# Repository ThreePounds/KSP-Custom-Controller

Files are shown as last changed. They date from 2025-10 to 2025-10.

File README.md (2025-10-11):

# KSP-Custom-Controller

This is a custom built game controller with 12 buttons and 7 analog axis using a teensy 4.0 and a 3D-printed housing designed for Kerbal Space Program. It's heavily inspired by [ksp-controller](https://github.com/malarcky/ksp-controller/) by *malarcky*.

## Setting up the custom controller

The teensy 4.0 micro controller is programmed using Arduino IDE and a custom USB type. To create the custom USB type, changes are made to the following files found in the teensy package. For me on windows, these files are located in `%appdata%\Local\Arduino15\packages\teensy\hardware\avr\1.59.0\cores\teensy4`.

### usb_desc.h

This code sets up the USB type and can be inserted any where after the first `#if defined()`:
```
#elif defined(USB_CUSTOM_CONTROLLER)
	#define VENDOR_ID 0x16C0
	#define PRODUCT_ID 0x0488
	#define BCD_DEVICE 0x0211
	#define MANUFACTURER_NAME {'T','h','r','e','e','P','o','u','n','d','s'}
	#define MANUFACTURER_NAME_LEN 11
	#define PRODUCT_NAME {'C','u','s','t','o','m',' ','K','S','P',' ','C','o','n','t','r','o','l','l','e','r'}
	#define PRODUCT_NAME_LEN 21
	#define EP0_SIZE 64
	#define NUM_ENDPOINTS 3
	#define NUM_INTERFACE 2
	#define SEREMU_INTERFACE 1 // Serial emulation
	#define SEREMU_TX_ENDPOINT 2
	#define SEREMU_TX_SIZE 64
	#define SEREMU_TX_INTERVAL 1
	#define SEREMU_RX_ENDPOINT 2
	#define SEREMU_RX_SIZE 32
	#define SEREMU_RX_INTERVAL 2
	#define JOYSTICK_INTERFACE 2 // Joystick
	#define JOYSTICK_ENDPOINT 3
	#define JOYSTICK_SIZE 16 // 16 = custom game controller, 12 = normal joystick, 64 = extreme joystick
	#define JOYSTICK_INTERVAL 1
	#define ENDPOINT2_CONFIG ENDPOINT_RECEIVE_INTERRUPT + ENDPOINT_TRANSMIT_INTERRUPT
	#define ENDPOINT3_CONFIG ENDPOINT_RECEIVE_UNUSED + ENDPOINT_TRANSMIT_INTERRUPT
```

### usb_joystick.h

This handles this axis and button assignment and must be added before the line `#elif JOYSTICK_SIZE == 64`.

```
#elif JOYSTICK_SIZE == 16 // Modified for 7-Axis, 12-Button, 16-Byte Report
	/**
	 * Sets the state of a button (1-12).
	 */
	void button(unsigned int num, bool val) {
		if (--num >= 12) return;
		// The 12 buttons fit in the first 16-bit word of the report.
		uint16_t *p = (uint16_t *)usb_joystick_data;
		if (val) {
			*p |= (1 << num);
		} else {
			*p &= ~(1 << num);
		}
		if (!manual_mode) usb_joystick_send();
	}

	// Axis Functions (public interface remains the same)
	void X(unsigned int position) { analog16(0, position); }
	void Y(unsigned int position) { analog16(1, position); }
	void Z(unsigned int position) { analog16(2, position); }
	void Xrotate(unsigned int position) { analog16(3, position); }
	void Yrotate(unsigned int position) { analog16(4, position); }
	void Zrotate(unsigned int position) { analog16(5, position); }

	/**
	 * Sets the position of the 7th axis (Slider).
	 * The original 'num' parameter is removed as we only have one slider.
	 */
	void slider(unsigned int position) {
		analog16(6, position);
	}
```

In the `private:` section before the line `#if JOYSTICK_SIZE == 64` add:

```
#if JOYSTICK_SIZE == 16
	void analog16(unsigned int num, unsigned int value) {
		if (num >= 7) return; // Safety check for 7 axes
		if (value > 1023) value = 1023;
		uint16_t scaled_value = (value << 6) | (value >> 4);
		
		uint16_t *p = (uint16_t *)usb_joystick_data;
		
		p[num + 1] = scaled_value;

		if (!manual_mode) usb_joystick_send(); 
	}
#endif
```

## 3D-printed housing

The housing was modelled using FreeCad 1.0.2. Included are .3mf files for the face plate and housing so they can be printed separately.

## The finished controller

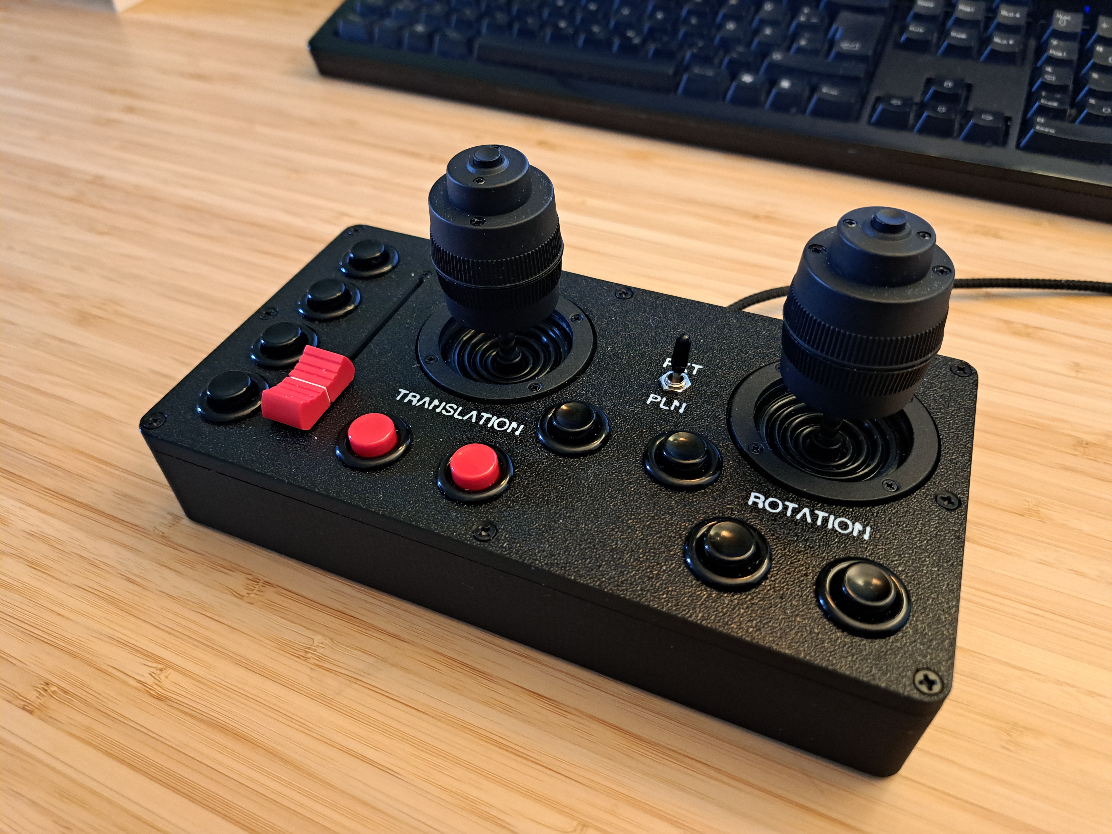
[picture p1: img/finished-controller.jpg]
the finished controller sitting on a desk


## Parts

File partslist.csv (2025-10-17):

Part | Link | Amount | Price | Total
LITZE RT Insulated braided copper wire, 10 m, 1 x 0.14 mm, red | https://secure.reichelt.com/de/en/insulated_braided_copper_wire_10_m_1_x_0_14_mm_red-p10297.html | 1 | 0.93 € | 0.93 €
LITZE BL Insulated braided copper wire, 10 m, 1 x 0.14 mm, blue | https://secure.reichelt.com/de/en/insulated_braided_copper_wire_10_m_1_x_0_14_mm_blue-p10292.html | 1 | 0.93 € | 0.93 €
LITZE GE Insulated braided copper wire, 10 m, 1 x 0.14 mm, yellow | https://secure.reichelt.com/de/en/insulated_braided_copper_wire_10_m_1_x_0_14_mm_yellow-p10294.html | 1 | 0.93 € | 0.93 €
LITZE SW Insulated braided copper wire, 10 m, 1 x 0.14 mm, black | https://secure.reichelt.com/de/en/insulated_braided_copper_wire_10_m_1_x_0_14_mm_black-p10298.html | 1 | 0.93 € | 0.93 €
KNOPF 4X1,2RT Fader knob for RS60112, rd | https://secure.reichelt.com/de/en/fader_knob_for_rs60112_rd-p73946.html | 1 | 1.25 € | 1.25 €
MS 165 Toggle switch, 1-pin, 10 A - 125 V AC, on-of | https://secure.reichelt.com/de/en/toggle_switch_1-pin_10_a_-_125_v_ac_on-off-p13139.html | 1 | 2.50 € | 2.50 €
MS 131 SW Push button miniature, 3 A - 125 V, 1x on, black | https://secure.reichelt.com/de/en/push_button_miniature_3_a_-_125_v_1x_on_black-p13137.html | 8 | 1.25 € | 10.00 €
MS 131 RT Push button miniature, 3 A - 125 V, 1x on, red | https://secure.reichelt.com/de/en/push_button_miniature_3_a_-_125_v_1x_on_red-p13136.html | 2 | 1.50 € | 3.00 €
RS60112-LIN10K ALPS mini sliding potentiometer, linear, stereo, 10K | https://secure.reichelt.com/de/en/alps_mini_sliding_potentiometer_linear_stereo_10k-p73865.html | 1 | 3.10 € | 3.10 €
TEENSY 4.0 Teensy 4.0, USB, without header | https://secure.reichelt.com/de/en/teensy_4_0_usb_without_header-p269006.html | 1 | 29.50 € | 29.50 €
Toocki 2.4A Micro USB Cable Fast Charging PD QC Quick Charge Micro Cable for Samsung S6 S7 Redmi Note Earphone Fan USB Data Cord | https://de.aliexpress.com/item/1005007053790042.html | 1 | 2.49 € | 2.49 €
JH-D400X-R4 JH-D400X-R2 4-axis potentiometer 400 series Rocker hall joystick dimensional 5K 10K sealed with button joystick | https://de.aliexpress.com/item/1005001844154962.html | 2 | 13.29 € | 26.58 €
Selbstklebend Gummi Scheiben Rund Gummipads Platte Φ 5mm bis 150mm Dicke 1-10mm, Durchmesser x Dicke: Φ10mm x 2mm, Menge (Stück): 10 Stück | https://www.ebay.de/itm/388732033051?var=655838041427 | 1 | 3.78 € | 3.78 €
M2 M2.5 M3 Senkkopfschrauben Kreuzschlitz Schrauben DIN 965, Schwarz Verzinkt, Gewindedurchmesser: M3 / 3mm, Menge (Stück): 10pcs, Länge: 10mm | https://www.ebay.de/itm/388667186919?var=655768644411 | 1 | 3.07 € | 3.07 €
M2 M2.5 M3 Senkkopfschrauben Kreuzschlitz Schrauben DIN 965, Schwarz Verzinkt, Gewindedurchmesser: M2 / 2mm, Menge (Stück): 10pcs, Länge: 5mm | https://www.ebay.de/itm/388667186919?var=655768644339 | 1 | 1.89 € | 1.89 €
3D printing, threaded inserts, VORON, M3, pack of 100 | https://www.reichelt.com/de/en/shop/product/3d_printing_threaded_inserts_voron_m3_pack_of_100-367014 | 1 | 9.49 € | 9.49 €
3D print, filament cost (approx.) |  | 1 | 10.51 € | 10.51 €
Total |  |  |  | 110.88 €

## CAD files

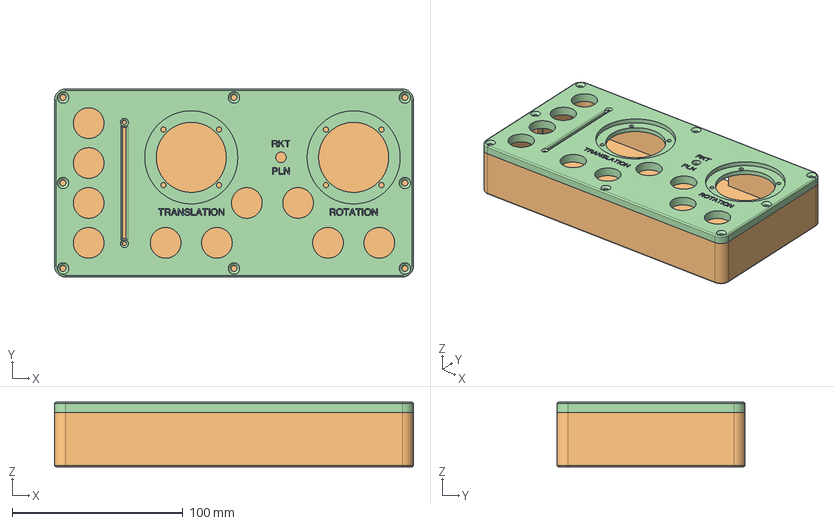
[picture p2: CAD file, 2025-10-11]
3d-models/ksp-controller.FCStd
210.0 x 110.0 x 38.0 mm
faceplate
housing
textElemets
faceplateCut

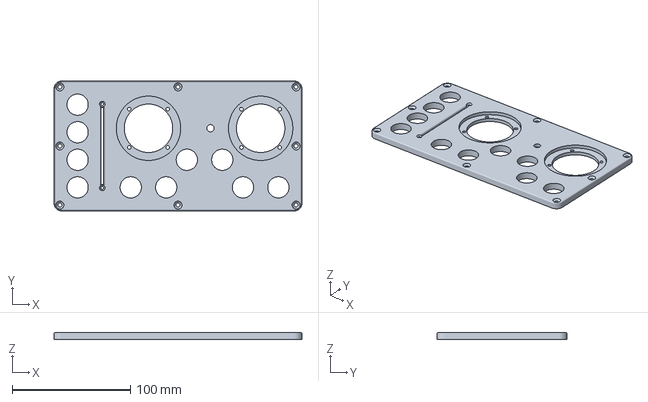
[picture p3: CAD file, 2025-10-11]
3d-models/ksp-controller_FacePlate.3mf
210.0 x 110.0 x 6.00 mm

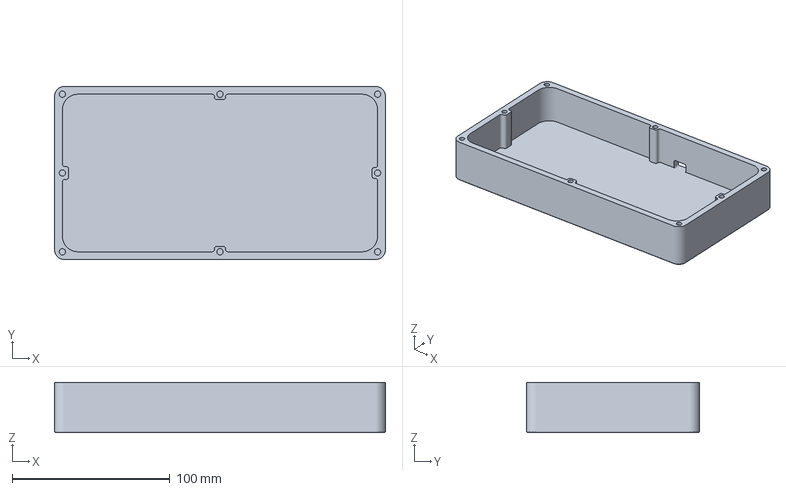
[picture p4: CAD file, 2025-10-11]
3d-models/ksp-controller_Housing.3mf
210.0 x 110.0 x 32.0 mm

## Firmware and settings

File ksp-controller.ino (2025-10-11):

//use UBS-Type "Custom Game Controller"
//see: https://github.com/ThreePounds/KSP-Custom-Controller for instructions

#include <Bounce2.h>  // debouncing

int BUTTON_PINS[] = { 0, 1, 5, 6, 11, 10, 9, 8, 7, 3, 4, 2 };
const int BUTTON_NUMBER = 12;
const int SWITCH_PIN = 12; // used for switching between spacecraft mode (normal) and aircraft mode (x-asis and z-axis on rotation joystick swapped)
const int JOY1_X_PIN = A4;
const int JOY1_Y_PIN = A3;
const int JOY1_Z_PIN = A5;
const int JOY2_X_PIN = A0;
const int JOY2_Y_PIN = A1;
const int JOY2_Z_PIN = A2;
const int SLIDER_PIN = A7;
const int ANALOG_MAX = 1023;
const int ANALOG_CENTER = 512;

Bounce2::Button buttonBouncers[BUTTON_NUMBER];
Bounce2::Button switchBouncer;

const int DEBOUNCE_MS = 10;

bool planeMode = false;

struct JoystickState {
  int xRaw;
  int yRaw;
  int zRaw;  
  float x;
  float y;
  float z;
};

JoystickState joystick1;
JoystickState joystick2;

int sliderRaw = 0;
float sliderValue = 0;

unsigned long lastUpdateTime = 0;
const int UPDATE_INTERVAL_MS = 5;

void setup() {
  for (int i = 0; i < BUTTON_NUMBER; i++) {
    buttonBouncers[i].attach(BUTTON_PINS[i], INPUT_PULLUP);
    buttonBouncers[i].interval(DEBOUNCE_MS);
  }
  switchBouncer.attach(SWITCH_PIN, INPUT_PULLUP);
  Joystick.useManualSend(true);
}

void loop() {
  switchBouncer.update();
  for (int i = 0; i < BUTTON_NUMBER; i++) {
    buttonBouncers[i].update();
  }

  if (millis() - lastUpdateTime >= UPDATE_INTERVAL_MS) {
    lastUpdateTime = millis();

    planeMode = !switchBouncer.read();

    joystick1.xRaw = ANALOG_MAX - analogRead(JOY1_X_PIN); //potentiometer soldered inverted by accident
    joystick1.yRaw = analogRead(JOY1_Y_PIN);
    joystick1.zRaw = analogRead(JOY1_Z_PIN);
    
    joystick1.x = applySmoothing(applyDeadzone(joystick1.xRaw), joystick1.x); 
    joystick1.y = applySmoothing(applyDeadzone(joystick1.yRaw), joystick1.y);
    joystick1.z = applySmoothing(applyDeadzone(joystick1.zRaw), joystick1.z);

    joystick2.xRaw = ANALOG_MAX - analogRead(JOY2_X_PIN); //potentiometer soldered inverted by accident
    joystick2.yRaw = ANALOG_MAX - analogRead(JOY2_Y_PIN); //potentiometer soldered inverted by accident
    joystick2.zRaw = analogRead(JOY2_Z_PIN);

    joystick2.x = applySmoothing(applyDeadzone(joystick2.xRaw), joystick2.x);
    joystick2.y = applySmoothing(applyDeadzone(joystick2.yRaw), joystick2.y);
    joystick2.z = applySmoothing(applyDeadzone(joystick2.zRaw), joystick2.z);

    //Right Joystick
    if (planeMode) {
      Joystick.X(applyExpoCurve(joystick1.z)); //assigning roll to jaw
      Joystick.Z(applyExpoCurve(joystick1.x)); //assigning jaw to roll
    } else {
      Joystick.X(applyExpoCurve(joystick1.x));
      Joystick.Z(applyExpoCurve(joystick1.z));
    }

    Joystick.Y(applyExpoCurve(joystick1.y));

    //Left Joystick
    Joystick.Xrotate(applyExpoCurve(joystick2.x));
    Joystick.Yrotate(applyExpoCurve(joystick2.y));
    Joystick.Zrotate(applyExpoCurve(joystick2.z));

    //slider
    sliderRaw = ANALOG_MAX - analogRead(SLIDER_PIN); //soldered inverted
    sliderValue = applySmoothing(sliderRaw, sliderValue);
    Joystick.slider(sliderValue);

    for (int i = 0; i < BUTTON_NUMBER; i++) {
      Joystick.button(i + 1, !buttonBouncers[i].read());
    }
    
    Joystick.send_now();
  }
}

int applyDeadzone(int value) {
  const int DEADZONE_RADIUS = 20;

  if (abs(value - ANALOG_CENTER) < DEADZONE_RADIUS) {
    return ANALOG_CENTER;
  }

  if (value < ANALOG_CENTER) {
    return map(value, 0, ANALOG_CENTER - DEADZONE_RADIUS, 0, ANALOG_CENTER); //lower range
  } else {
    return map(value, ANALOG_CENTER + DEADZONE_RADIUS, ANALOG_MAX, ANALOG_CENTER, ANALOG_MAX); //upper range
  }
}

float applySmoothing(int rawValue, float value) {
  const float SMOOTHING_FACTOR = 0.2; //0 = no smoothing, 1.0 = heavy smoothing
  return (rawValue * SMOOTHING_FACTOR) + (value * (1.0 - SMOOTHING_FACTOR));
}

int applyExpoCurve(float value) {
  const float EXPO_INTENSITY = 0.6; //adjust this: 0.0=linear, 1.0=fully cubic
  float normalizedValue = (value - ANALOG_CENTER) / (float)ANALOG_CENTER;
  float curvedValue = normalizedValue * normalizedValue * normalizedValue;
  float blendedValue = (normalizedValue * (1.0 - EXPO_INTENSITY)) + (curvedValue * EXPO_INTENSITY);
  int finalValue = (blendedValue * ANALOG_CENTER) + ANALOG_CENTER;
  return constrain(finalValue, 0, ANALOG_MAX);
}
